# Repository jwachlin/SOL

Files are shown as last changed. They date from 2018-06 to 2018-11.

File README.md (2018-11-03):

# SOL
Long-term solar intensity sensing

People considering a photovoltaic installation on their property should be able to make a data-driven decision about the viability of such a system. While projects such as Google's Project Sunroof can provide large-scale estimates of solar intensity from satellite images, SOL will be able to provide data that incorporates local effects such as roof slope and direction, tree cover, or obstruction from nearby buildings.

See project logs for SOL at the Hackaday project page: https://hackaday.io/project/158984-sol-long-term-solar-intensity-sensing

R2 included a variety of upgrades to lower cost and improve performance:

- ADC with PGA allows better measurement accuracy (ESP32 ADC is highly nonlinear)
- Temperature sensor added (ESP32 internal temperature sensor has very poor performance)
- RTC added for accurate time monitoring without connecting to network
- Smaller PCB with smaller battery (14500 battery)
- Fixed dimensions and location of mounting hole (V1 didn't fit well in case)
- Easier programming by moving required pins to pin headers

However, R2 had some issues:

- Mistake on trace routing held temperature sensor output to ground, making it not work
- Forgot to add load capacitors on RTC crystal, so RTC does not work
- PCB vias not covered with soldermask underneath battery connectors, which would cause shorts
- The charger IC has a large pad underneath it, which was not included in its Eagle part
- The battery silkscreen was left on top of the PCB, when it should have been on the bottom. Not a functional issue, since battery connectors can be attached through either side
- Decoupling capacitor was not put near the ADC, when it should have been. The ADC still seems to work fine, but this should still be fixed

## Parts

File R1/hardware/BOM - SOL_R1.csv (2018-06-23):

Part | Value | Mouser Part # | Quantity | Description | Package Type | Placement | Top/Bottom
ESP32-WROOM | N/A | 356-ESP-WROOM-32 | 1 | ESP32 MCU | N/A | SMD | Top
OPA344 | N/A | 595-OPA344NA/3K | 1 | Opamp | SOT-23-5 | SMD | Top
I2C EEPROM | 512 kbit | 863-CAT24C512WI-GT3 | 1 | EEPROM | SOIC-8 | SMD | Top
Voltage Regulator | 3.3V | 998-MIC5205-3.3YM5TR | 1 | VReg | SOT-23-5 | SMD | Top
Battery Charger | N/A | 700-MAX1555EZK+T | 1 | Charger | SOT-23-5 | SMD | Top
MOSFET | N/A | 512-2N7002 | 2 | MOSFET | SOT-23-3 | SMD | Top
Waterproof Case | N/A | 546-RP1065 | 1 | Case | N/A | N/A | N/A
Solar Panel | 0.5W | 713-313070004 | 1 | Solar Panel | N/A | N/A | N/A
Panel Mount LED | N/A | 593-L65DG2L | 1 | LED | N/A | N/A | N/A
LED O-Ring | N/A | 593-SPC301 | 1 | ORing | N/A | N/A | N/A
Ceramic Decouple Capacitor | 1 uF | 710-885012107015 | 5 | Capacitor | 0805 | SMD | Top
Battery Holder | N/A | 534-54 | 2 | Battery Holder | N/A | Through Hole | Bottom
Zener Diode | 6.8V | 821-BZX55B6V8R0G | 1 | Clamp diode | Axial | Through Hole | Top
Solar Panel Connector | 2mm pitch | 474-PRT-09749 | 1 | Connector | N/A | Through Hole | Top
Sense Resistor, 1% | 0.75 Ohm | 71-RCWH0805R750FKEA | 1 | Resistor | 0805 | SMD | Top
Resistor | 5.1 Ohm | 603-RT0603DRD075R1L | 1 | Resistor | 0603 | SMD | Top
I2C Pullup Resistor | 4.7 kOhm | 603-AC0603FR-074K7L | 2 | Resistor | 0603 | SMD | Top
Resistor | 330 Ohm | 603-RC0603FR-13330RL | 3 | Resistor | 0603 | SMD | Top
Resistor, 0.5% | 47 kOhm | 754-RR0816P-473D | 2 | Resistor | 0603 | SMD | Top
Resistor, 0.5% | 15 kOhm | 754-RR0816P-153D | 1 | Resistor | 0603 | SMD | Top
Resistor, 0.5% | 100 kOhm | 754-RR0816P-104D | 1 | Resistor | 0603 | SMD | Top
Resistor, 0.5% | 1 kOhm | 754-RR0816P-102D | 1 | Resistor | 0603 | SMD | Top

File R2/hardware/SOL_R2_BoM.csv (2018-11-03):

Part | Manufacturer Part Number | Quantity
U2 | ESP32-WROOM-32 | 1
U5 | MCP6001T-I/OT | 1
U3 | 24AA32AFT-I/OT | 1
U8 | MCP7940N-I/MS | 1
Y1 | ABS07-166-32.768KHZ-T | 1
U4 | ADS1015IDGSR | 1
U6 | TLV75533PDBVR | 1
U7 | DIO5158XM8 | 1
Q1 | NX7002AKVL | 1
N/A | RP1065 | 1
N/A | 313070004 | 1
C1,C2,C3,C4,C5 | 885012207022 | 6
BT1 | 92 | 2
D1 | BZX84J-B6V2,115 | 1
R4 | CRL0805-FW-R750ELF | 1
R5 | CRL0603-FW-5R10ELF | 1
R3,R8,R12,R14 | RC0603FR-07330RL | 4
R9,R11,R17,R6 | RR0816P-473-D | 4
R7,R10 | RR0816P-153-D | 2
R2 | RR0816P-104-D | 1
R15,R16,R1 | RR0816P-102-D | 3
R18,R19 | RC0603FR-07470KL | 2
N/A | R4-40X3/8 | 1
N/A | 4694 | 1
N/A | 31428 | 1
D3 | DF3A5.6LFU,LF | 1
U1 | MCP9700T-E/TT | 1
IO0,IO2 | 929870-01-02-RB | 1
PROG | 929870-01-04-RA | 1
D2 | 150060RS75000 | 1

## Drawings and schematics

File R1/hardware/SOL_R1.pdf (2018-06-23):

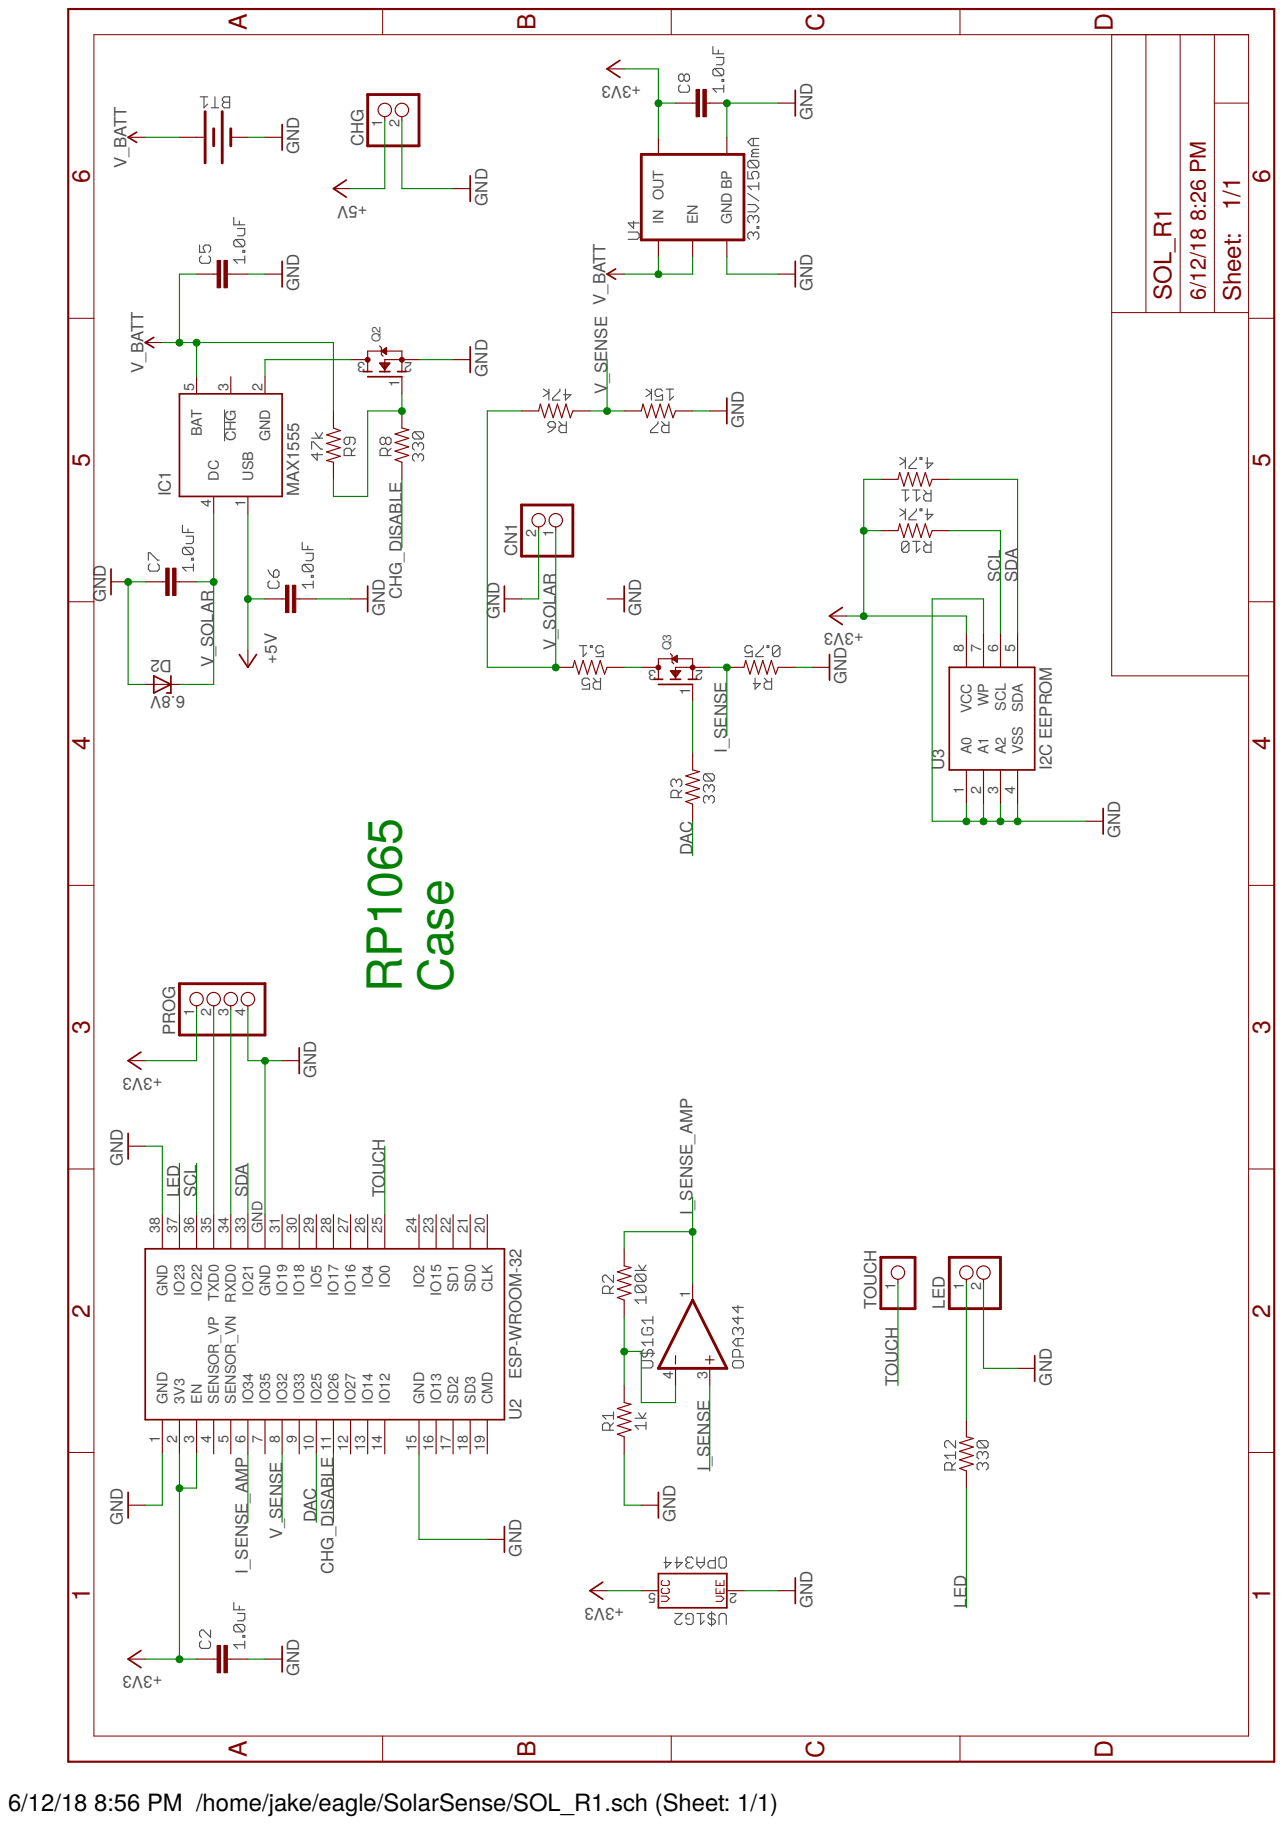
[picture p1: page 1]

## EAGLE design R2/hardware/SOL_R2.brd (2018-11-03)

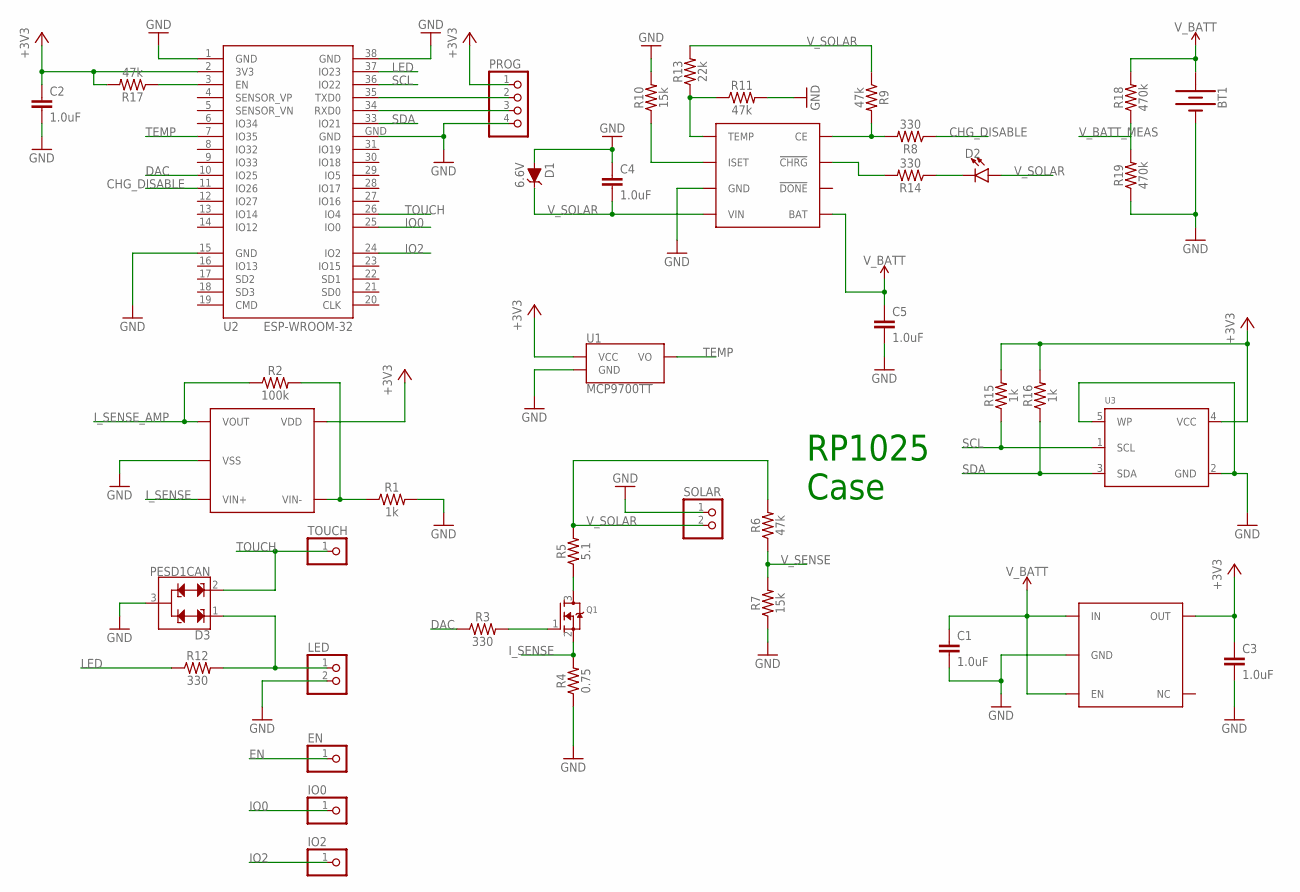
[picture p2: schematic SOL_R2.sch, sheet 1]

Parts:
BT1: BATTERY-AA
C1, C2, C3, C4, C5: 1.0uF; 0805
D1: 6.6V; SOD-323
D2: LED0603; LED-0603
D3: PESD1CAN; SOT23-3
EN: PINHD-1X1; 1X01
IO0, IO2: PINHD-1X1; 1X01
LED: PINHD-1X2; 1X02
PROG: PINHD-1X4; 1X04
Q1: MOSFET-NREFLOW; SOT23-R
R1, R15, R16: 1k; 0603
R2: 100k; 0603
R3, R8, R12, R14: 330; 0603
R4: 0.75; 0805
R5: 5.1; 0603
R6, R9, R11, R17: 47k; 0603
R7, R10: 15k; 0603
R13: 22k; 0603
R18, R19: 470k; 0603
SOLAR: PINHD-1X2; 1X02
TOUCH: PINHD-1X1; 1X01
U1: MCP9700TT; SOT23-3
U2: ESP-WROOM-32
U3: EEPROM_I2C_MCP24AA32; SOT23-5
U5: MCP6001; SOT23-5L
U6: TLV755; SOT23-DBV
U7: DIO5158XM8; MSOP8

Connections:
+3V3: C2.1, C3.1, PROG.1, R15.2, R16.2, R17.2, U1.1 (VCC), U2.2 (3V3), U3.4 (VCC), U5.5 (VDD), U6.5 (OUT); also elsewhere on the board
CHG_DISABLE: R8.1, U2.11 (IO26)
DAC: R3.1, U2.10 (IO25)
EN: EN.1, R17.1, U2.3 (EN)
GND: BT1.GND@1 (-), C1.2, C2.2, C3.2, C4.1, C5.2, D1.A, D3.3, LED.2, PROG.4, R1.2, R4.1, R7.1, R10.2, R11.2, R19.1, SOLAR.1, U1.3 (GND), U2.1 (GND), U2.15 (GND), U2.38 (GND), U2.GND, U3.2 (GND), U3.5 (WP), U5.2 (VSS), U6.2 (GND), U7.3 (GND); also elsewhere on the board
IO0: IO0.1, U2.25 (IO0)
IO2: IO2.1, U2.24 (IO2)
I_SENSE: Q1.2 (S), R4.2, U5.3 (VIN+)
I_SENSE_AMP: R2.1, U5.1 (VOUT); also elsewhere on the board
LED: R12.1, U2.37 (IO23)
unnamed: R10.1, U7.2 (ISET)
unnamed: D3.1, LED.1, R12.2
unnamed: R11.1, R13.1, U7.1 (TEMP)
unnamed: Q1.1 (G), R3.2
unnamed: R1.1, R2.2, U5.4 (VIN-)
unnamed: Q1.3 (D), R5.1
unnamed: R8.2, R9.2, U7.8 (CE)
unnamed: R14.2, U7.7 (!CHRG!)
unnamed: D2.C, R14.1
RXD: PROG.3, U2.34 (RXD0)
SCL: R15.1, U2.36 (IO22), U3.1 (SCL); also elsewhere on the board
SDA: R16.1, U2.33 (IO21), U3.3 (SDA); also elsewhere on the board
TEMP: U1.2 (VO), U2.7 (IO35)
TOUCH: D3.2, TOUCH.1, U2.26 (IO4)
TXD: PROG.2, U2.35 (TXD0)
V_BATT: BT1.PWR@1 (+), C1.1, C5.1, R18.2, U6.1 (IN), U6.3 (EN), U7.5 (BAT)
V_BATT_MEAS: R18.1, R19.2; also elsewhere on the board
V_SENSE: R6.1, R7.2; also elsewhere on the board
V_SOLAR: C4.2, D1.C, D2.A, R5.2, R6.2, R9.1, R13.2, SOLAR.2, U7.4 (VIN)

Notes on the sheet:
RP1025 Case

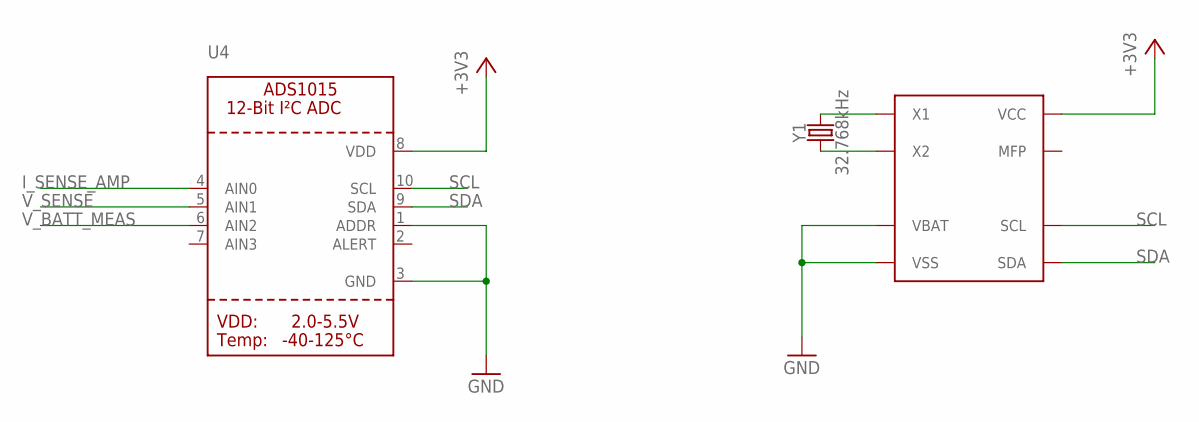
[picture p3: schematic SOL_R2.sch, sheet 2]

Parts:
U4: ADC_ADS1015; MSOP10
U8: MCP7940; MSOP8
Y1: 32.768kHz; CRYSTAL-SMD-3.2X1.5MM

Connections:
+3V3: U4.8 (VDD), U8.8 (VCC); also elsewhere on the board
GND: U4.1 (ADDR), U4.3 (GND), U8.3 (VBAT), U8.4 (VSS); also elsewhere on the board
I_SENSE_AMP: U4.4 (AIN0); also elsewhere on the board
unnamed: U8.1 (X1), Y1.P$2 (2)
unnamed: U8.2 (X2), Y1.P$1 (1)
SCL: U4.10 (SCL), U8.6 (SCL); also elsewhere on the board
SDA: U4.9 (SDA), U8.5 (SDA); also elsewhere on the board
V_BATT_MEAS: U4.6 (AIN2); also elsewhere on the board
V_SENSE: U4.5 (AIN1); also elsewhere on the board

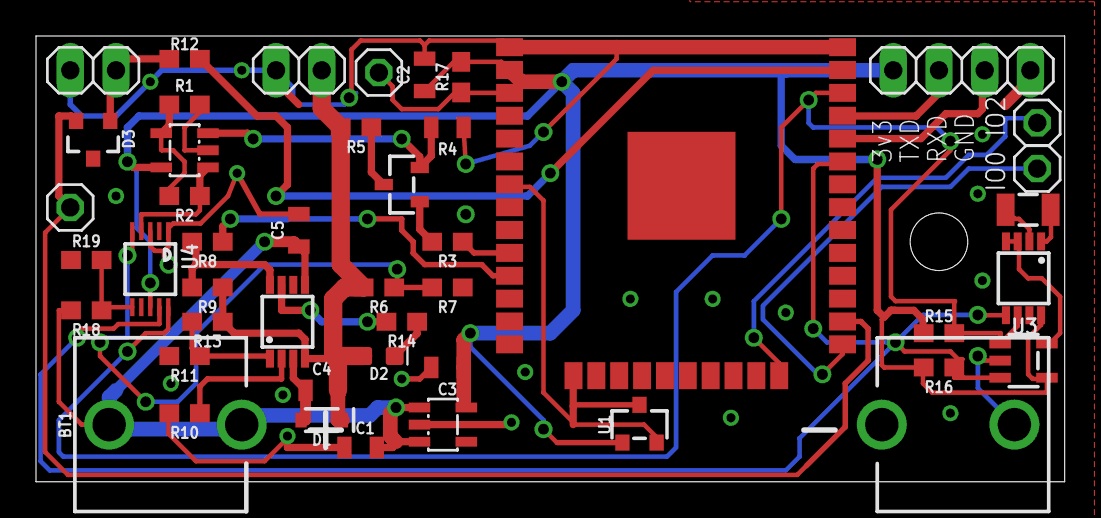
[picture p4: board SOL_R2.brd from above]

Board: 2 copper layers, 57.1 x 24.8 mm, 45 parts (0 on the bottom side), 31 nets.

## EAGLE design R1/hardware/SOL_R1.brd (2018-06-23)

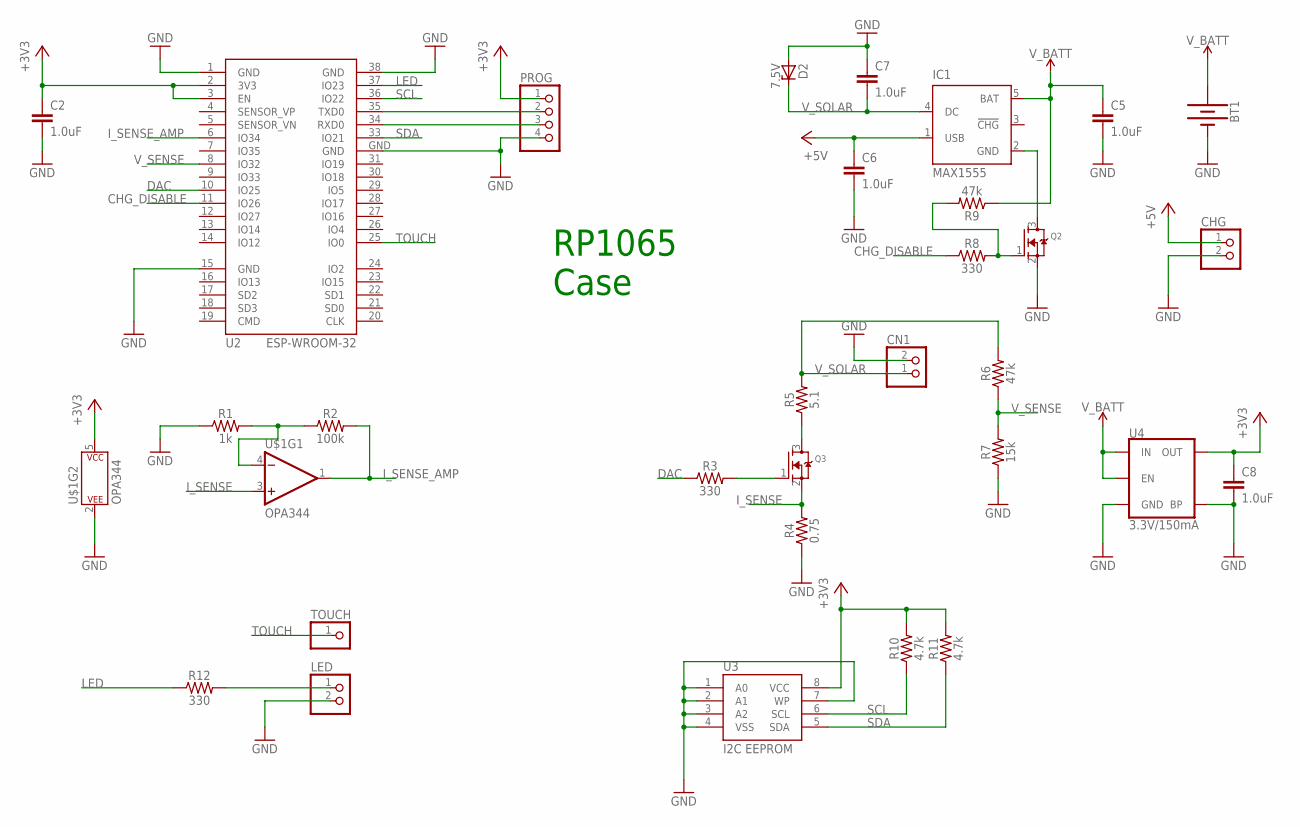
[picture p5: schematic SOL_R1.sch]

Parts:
BT1: BATTERY-18650; BATTERY_18650-HOLDER
C2, C5, C6, C7, C8: 1.0uF; 0805
CHG: PINHD-1X2; 1X02
CN1: JST_2PIN-THM-RA; JST-PH-2-THM-RA
D2: 7.5V; ZDIO-5
IC1: MAX1555; SOT23-5L
LED: PINHD-1X2; 1X02
PROG: PINHD-1X4; 1X04
Q2, Q3: MOSFET-NREFLOW; SOT23
R1: 1k; 0603
R2: 100k; 0603
R3, R8, R12: 330; 0603
R4: 0.75; 0805
R5: 5.1; 0603
R6, R9: 47k; 0603
R7: 15k; 0603
R10, R11: 4.7k; 0603
TOUCH: PINHD-1X1; 1X01
U2: ESP-WROOM-32
U3: I2C EEPROM; SO08-EIAJ
U4: 3.3V/150mA; SOT23-5
U$1: OPA344; SOT23-5

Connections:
+3V3: C2.1, C8.1, PROG.1, R10.2, R11.2, U2.2 (3V3), U2.3 (EN), U3.8 (VCC), U4.5 (OUT), U$1.5 (P$V+)
+5V: C6.1, CHG.1, IC1.1 (USB)
CHG_DISABLE: R8.1, U2.11 (IO26)
DAC: R3.1, U2.10 (IO25)
GND: BT1.GND@1 (-), C2.2, C5.2, C6.2, C7.1, C8.2, CHG.2, CN1.2 (1), D2.A, LED.2, PROG.4, Q2.2 (S), R1.1, R4.1, R7.1, U2.1 (GND), U2.15 (GND), U2.38 (GND), U2.GND, U3.1 (A0), U3.2 (A1), U3.3 (A2), U3.4 (VSS), U3.7 (WP), U4.2 (GND), U4.4 (BP), U$1.2 (P$V-)
I_SENSE: Q3.2 (S), R4.2, U$1.3 (+IN)
I_SENSE_AMP: R2.2, U2.6 (IO34), U$1.1 (OUT)
LED: R12.1, U2.37 (IO23)
unnamed: R1.2, R2.1, U$1.4 (-IN)
unnamed: LED.1, R12.2
unnamed: Q3.1 (G), R3.2
unnamed: IC1.2 (GND), Q2.3 (D)
unnamed: Q3.3 (D), R5.1
unnamed: Q2.1 (G), R8.2, R9.2
RXD: PROG.3, U2.34 (RXD0)
SCL: R10.1, U2.36 (IO22), U3.6 (SCL)
SDA: R11.1, U2.33 (IO21), U3.5 (SDA)
TOUCH: TOUCH.1, U2.25 (IO0)
TXD: PROG.2, U2.35 (TXD0)
V_BATT: BT1.PWR@1 (+), C5.1, IC1.5 (BAT), R9.1, U4.1 (IN), U4.3 (EN)
V_SENSE: R6.1, R7.2, U2.8 (IO32)
V_SOLAR: C7.2, CN1.1 (2), D2.C, IC1.4 (DC), R5.2, R6.2

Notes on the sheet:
RP1065 Case

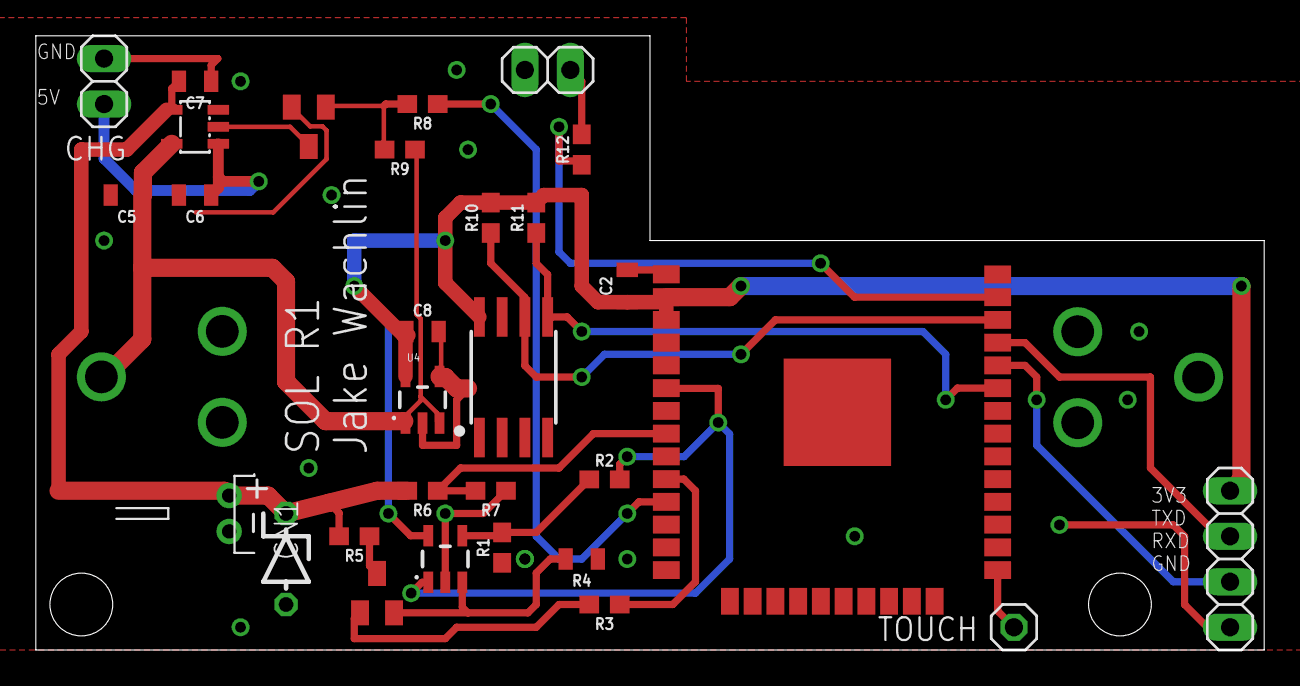
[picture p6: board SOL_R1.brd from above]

Board: 2 copper layers, 68.6 x 34.3 mm, 31 parts (1 on the bottom side), 22 nets.

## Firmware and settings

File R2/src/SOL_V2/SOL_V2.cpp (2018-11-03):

/*
MIT License

Copyright (c) 2018 by Jacob Wachlin

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
THE SOFTWARE IS PROVIDED "AS IS", WITHOUT WARRANTY OF ANY KIND, EXPRESS OR
IMPLIED, INCLUDING BUT NOT LIMITED TO THE WARRANTIES OF MERCHANTABILITY,
FITNESS FOR A PARTICULAR PURPOSE AND NONINFRINGEMENT. IN NO EVENT SHALL THE
AUTHORS OR COPYRIGHT HOLDERS BE LIABLE FOR ANY CLAIM, DAMAGES OR OTHER
LIABILITY, WHETHER IN AN ACTION OF CONTRACT, TORT OR OTHERWISE, ARISING FROM,
OUT OF OR IN CONNECTION WITH THE SOFTWARE OR THE USE OR OTHER DEALINGS IN THE
SOFTWARE.
*/

/**
 * @file SOL_V2.cpp
 * @author Jacob Wachlin
 * @date 26 Sept 2018
 * @brief SOL_V2 arduino compatible library for the ESP32
 */

#include <Arduino.h>
#include <Wire.h>
#include <WiFi.h>
#include <DNSServer.h>
#include <WiFiManager.h>          //https://github.com/tzapu/WiFiManager
#include <Adafruit_ADS1015.h>
#include <mcp7940_sol.h>

#include "time.h"

#include "SOL_V2.h"

const char* ntpServer = "pool.ntp.org";
const long  gmtOffset_sec = 0;
const int   daylightOffset_sec = 0;

RTC_DATA_ATTR uint32_t sleepCount = 0;
RTC_DATA_ATTR uint32_t lastNTPTime = 0;

static uint16_t last_write_address;
static uint8_t ssid_length;
static char ssid[64];
static uint8_t pswd_length;
static char pswd[64];
static uint32_t device_ID;
static Adafruit_ADS1015 ads;

static adsGain_t ADC_gains[5] = {GAIN_ONE, GAIN_TWO, GAIN_FOUR, GAIN_EIGHT, GAIN_SIXTEEN};
static float ADC_max_v[5] = {4.096, 2.048, 1.024, 0.512, 0.256};

/**
 * @brief Handles touch sensor input
 *
 */
static void SOL_handletouch(void)
{
	#ifdef SOL_DEBUG
	Serial.println("Touch sensed");
	#endif
	uint8_t dummy = 0;
}

/**
 * @brief Performs initialization for SOL
 *
 * 	This function setups up GPIO, I2C, and touch sensor interrupt
 */
void SOL_begin()
{
	#ifdef SOL_DEBUG
	Serial.begin(115200);
	#endif

	Wire.begin(SDA_PIN,SCL_PIN,400000);

	//Set ID with MAC address
	device_ID = (uint32_t) ESP.getEfuseMac();

	#ifdef SOL_DEBUG
	// Start LED pin low
	pinMode(LED_PIN, OUTPUT);
	digitalWrite(LED_PIN, LOW);
	#endif

	// Set charge disable pin low
	pinMode(CHG_DISABLE_PIN, OUTPUT);
	digitalWrite(CHG_DISABLE_PIN, LOW);

	// Set up touch interrupts
	// TODO allow wakeup from deepsleep
	touchAttachInterrupt(TOUCH_PIN, SOL_handletouch, 40); // TODO set threshold intelligently?

	// Set up ADC
	ads.setGain(GAIN_ONE);  // 1x gain   +/- 4.096V  1 bit = 2mV
	ads.begin();

	// Set up RTC
	RTCSetup();

	#ifdef SOL_DEBUG
	Serial.println("Starting up");
	#endif
}

/**
 * @brief Manages SOL task upon wakeup, triggering data reading and uploading when necessary
 *
 */
void SOL_task()
{
	#ifdef SOL_DEBUG
	Serial.println("Running Task");
	#endif

	sleepCount = sleepCount + 1;

	esp_sleep_wakeup_cause_t wakeup_reason;
  	wakeup_reason = esp_sleep_get_wakeup_cause();
	if(wakeup_reason == ESP_SLEEP_WAKEUP_TOUCHPAD)
	{
		#ifdef SOL_DEBUG
		Serial.println("Starting provisioning");
		#endif
		SOL_startProvisioning();
	}

	// If not provisioned yet, don't save data
	else if( SOL_hasWiFiCredentials() )
	{
		// Run power sweep, save data
		SOL_generateDataPacket();

		// Determine if it is time to upload data
		uint16_t next_storage_address;
		SOL_readEEPROMNByte(EEPROM_ADDRESS_NEXT_STORAGE_ADDRESS, (uint8_t *)&next_storage_address, 2);

		uint16_t datapoints = (next_storage_address - EEPROM_ADDRESS_DATA_RANGE_START_ADDRESS) / sizeof(data_packet_t);

		#ifdef SOL_DEBUG
		Serial.print("Number of datapoints: ");
		Serial.println(datapoints);
		#endif

		if(datapoints >= SENSE_COUNT_TO_SEND)
		{
			// Connect with 10 second timeout and upload 
			if(SOL_connectToWiFi(10))
			{	
				#ifdef SOL_DEBUG
				Serial.println("Connected to wifi, now uploading");
				#endif
				SOL_upload();

				// Update time to reduce drift
				SOL_set_time_from_ntp();
				sleepCount = 0;
			}
		}
	}

	// Enter deep sleep
	SOL_deepsleep(SLEEP_TIME_SECONDS);
}

/**
 * @brief Checks in EEPROM if  WiFi credentials are available and loads them if so
 *
 * @return 1 if credentials are available, otherwise 0
 */
uint8_t SOL_hasWiFiCredentials()
{
	uint8_t hasCred = SOL_readEEPROMByte(EEPROM_ADDRESS_WIFI_CREDENTIALS_AVAILABLE);

	if(hasCred == 1)
	{
		// Get credentials
		ssid_length = SOL_readEEPROMByte(EEPROM_ADDRESS_WIFI_SSID_LENGTH);
		pswd_length = SOL_readEEPROMByte(EEPROM_ADDRESS_WIFI_PSWD_LENGTH);

		#ifdef SOL_DEBUG
		Serial.print("SSID length: ");
		Serial.println(ssid_length);
		Serial.print("PSWD length: ");
		Serial.println(pswd_length);
		#endif

		// Guard against too long
		if(ssid_length > 64) {ssid_length = 64;}
		if(pswd_length > 64) {pswd_length = 64;}

		
		for(uint8_t i = 0; i < ssid_length; i++)
		{
			ssid[i] = SOL_readEEPROMByte(EEPROM_ADDRESS_WIFI_SSID_START+i);
		}

		for(uint8_t i = 0; i < pswd_length; i++)
		{
			pswd[i] = SOL_readEEPROMByte(EEPROM_ADDRESS_WIFI_PSWD_START+i);
		}

		#ifdef SOL_DEBUG
		String str_ssid(ssid);
		Serial.print("SSID: ");
		Serial.println(str_ssid);
		String str_pswd(pswd);
		Serial.print("PSWD: ");
		Serial.println(str_pswd);
		#endif
		
	}
	else
	{
		hasCred = 0;
	}

	#ifdef SOL_DEBUG
	Serial.print("Cred: ");
	Serial.println(hasCred);
	#endif

	return hasCred;
}

/**
 * @brief Attempts to connect to Wifi
 *
 * @param timeout The connection attempt timeout in seconds
 *
 * @return 1 if connected, otherwise 0
 */
uint8_t SOL_connectToWiFi(uint16_t timeout)
{
	#ifdef SOL_DEBUG
	Serial.println("Attempting to connect to WiFi");
	Serial.println(ssid_length);
	Serial.println(pswd_length);
	#endif

	// Get correct parts of ssid and pswd TODO clean up?
	char ssid_part[ssid_length+1];
	char pswd_part[pswd_length+1];
	for(uint8_t i = 0; i < ssid_length; i++) ssid_part[i] = ssid[i];
	for(uint8_t i = 0; i < pswd_length; i++) pswd_part[i] = pswd[i];

	// Null terminate
	ssid_part[ssid_length] = '\0';
	pswd_part[pswd_length] = '\0';

	WiFi.begin(ssid_part,pswd_part);

	#ifdef SOL_DEBUG
	String str_ssid(ssid_part);
	String str_pswd(pswd_part);
	Serial.print("SSID: ");
	Serial.println(str_ssid);
	Serial.print("PSWD: ");
	Serial.println(str_pswd);

	Serial.println("Connecting");
	#endif

	uint8_t success = 1;
	long start_time = millis();
	while (WiFi.status() != WL_CONNECTED) //not connected
	{
		delay(50);
		#ifdef SOL_DEBUG
		Serial.print(".");
		#endif
		if((millis() - start_time) > (timeout*1000))
		{
			#ifdef SOL_DEBUG
			Serial.println("Could not connect. Timeout");
			#endif

			success = 0;
			break;
		}
	}
	return success;
}
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

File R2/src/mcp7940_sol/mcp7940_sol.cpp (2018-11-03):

#include <Arduino.h>
#include <Wire.h>

#include "mcp7940_sol.h"

static void startRTCOscillator(void)
{
	Wire.beginTransmission(MCP7940_ADDRESS);
	Wire.write(byte(MCP7940_SECONDS));
	Wire.endTransmission();

	Wire.requestFrom(MCP7940_ADDRESS, 1);
	uint8_t seconds_register = Wire.read();

	seconds_register |= (1 << 7);

	Wire.beginTransmission(MCP7940_ADDRESS);
	Wire.write(byte(MCP7940_SECONDS));
	Wire.write(seconds_register);
	Wire.endTransmission();
}

static void stopRTCOscillator(void)
{
	Wire.beginTransmission(MCP7940_ADDRESS);
	Wire.write(byte(MCP7940_SECONDS));
	Wire.endTransmission(false);

	Wire.requestFrom(MCP7940_ADDRESS, 1);
	uint8_t seconds_register = Wire.read();

	seconds_register &= 0x7F;

	Wire.beginTransmission(MCP7940_ADDRESS);
	Wire.write(byte(MCP7940_SECONDS));
	Wire.write(seconds_register);
	Wire.endTransmission(false);
}

void RTCSetup(void)
{
	stopRTCOscillator();

	Wire.beginTransmission(MCP7940_ADDRESS);
  	Wire.write(byte(MCP7940_CALIBRATION));
  	Wire.write(0x00); // turn off calibration
  	Wire.endTransmission(false);

  	Wire.beginTransmission(MCP7940_ADDRESS);
  	Wire.write(byte(MCP7940_CONTROL_REG));
  	Wire.write(0x00);
  	Wire.endTransmission(false);

  	startRTCOscillator();
}

void setRTCTime(uint8_t seconds, uint8_t minutes, uint8_t hour, 
	uint8_t date, uint8_t month, uint16_t year)
{
	uint8_t raw_data[7];

	uint8_t ten_seconds = seconds / 10;
	raw_data[0] = ((ten_seconds & 0xF) << 4) + ((seconds - 10*ten_seconds) & 0xF);
	raw_data[0] |= (1 << 7);

	uint8_t ten_minutes = minutes / 10;
	raw_data[1] = ((ten_minutes & 0xF) << 4) + ((minutes - 10*ten_minutes) & 0xF);

	uint8_t ten_hour = hour / 10;
	raw_data[2] = ((ten_hour & 0x1) << 4) + ((hour - 10*ten_hour) & 0xF); // Set to 24 hour mode by bit 5 = 0

	raw_data[3] = 0; // TODO set day?

	uint8_t ten_date = date / 10;
	raw_data[4] = ((ten_date & 0x3) << 4) + ((date - 10*ten_date) & 0xF);

	uint8_t ten_month = month / 10;
	raw_data[5] = ((ten_month & 0x1) << 4) + ((month - 10*ten_month) & 0xF);

	uint8_t ten_year = year / 10;
	raw_data[6] = ((ten_year & 0xF) << 4) + ((year - 10*ten_year) & 0xF);

	//stopRTCOscillator();

	Wire.beginTransmission(MCP7940_ADDRESS);
	Wire.write(byte(MCP7940_SECONDS));
	for(int i = 0; i < 7; i++)
	{
		Wire.write(raw_data[i]);
	}
	Wire.endTransmission();

	startRTCOscillator();
}

uint32_t getRTCTime(void)
{
	startRTCOscillator();

	uint8_t raw_data[7];

	Wire.beginTransmission(MCP7940_ADDRESS);
	Wire.write(byte(0));
	Wire.endTransmission();

	Wire.requestFrom(MCP7940_ADDRESS, 7);
	for(int i = 0; i < 7; i++)
	{
		raw_data[i] = Wire.read();
	}

	// Parse raw data
	uint32_t seconds = (raw_data[0] & 0xF) + 10*((raw_data[0] & 0x70) >> 4);
	uint32_t minutes = (raw_data[1] & 0xF) + 10*((raw_data[1] & 0x70) >> 4);
	uint32_t hour = (raw_data[2] & 0xF) + 10*((raw_data[2] & 0x10) >> 4);
	uint32_t date = (raw_data[4] & 0xf)+ 10*((raw_data[4] & 0x30) >> 4);
	uint32_t month = (raw_data[5] & 0xF) + 10*((raw_data[5] & 0x10) >> 4);
	uint32_t year = (raw_data[6] & 0xF) + 10*((raw_data[6] & 0xF0) >> 4);

	Serial.println(seconds);
	Serial.print("Osc: ");
	Serial.println(raw_data[3] & (1 << 5));
	Serial.println(raw_data[0] & (1 << 7));

	//Serial.println(minutes);
	//Serial.println(hour);
	//Serial.println(date);
	//Serial.println(month);
	//Serial.println(year);

	// Time is seconds since January 1st, 1970
	uint32_t current_time = seconds;
	current_time += minutes * 60;
	current_time += hour * 3600;
	current_time += date * 86400;
	current_time += month * 2592000;
	current_time += year * 31104000; // TODO include leap year

	startRTCOscillator();

	return current_time;
}

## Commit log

2018-06-23 Added hardware files and BoM for first version
    [BOM - SOL_R1.csv, SOL_R1.brd, SOL_R1.sch]
2018-06-23 Adds Arduino ESP32 compatible library for SOL
2018-06-24 Remove unneeded delays to lower power. Use WiFiManager for provision
    WiFiManager library handles wifi provisioning, automatically presenting available networks. I2C speed increased to 400 kHz and unnecessary delays were removed, so system is awake for shorter times, lowering power consumption.
    [SOL.cpp]
2018-11-03 Rearranges repo. Adds V2 design documents and firmware. Updated readme about v2 issues
    [BOM - SOL_R1.csv, SOL_R1.brd, SOL_R1.sch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]

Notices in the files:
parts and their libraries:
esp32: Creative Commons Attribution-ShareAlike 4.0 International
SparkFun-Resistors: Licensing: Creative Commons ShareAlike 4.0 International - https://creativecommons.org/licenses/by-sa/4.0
